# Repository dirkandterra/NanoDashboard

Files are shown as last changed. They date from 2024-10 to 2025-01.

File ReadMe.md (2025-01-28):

# _ESP_Dashboard_  

_This project uses the a Nano with a MCP2515 to drive a 2004 Dodge Intrepid Dashboard._

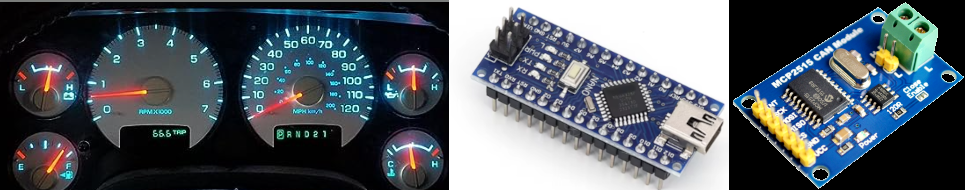
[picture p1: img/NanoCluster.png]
  

## How to use  

### Hardware Required  
* 2004 Dodge Intrepid Instrument Panel
* Connection:  

| Signal | Intrepid  | Nano |
|---|---|---|
| 5V | 5V		| 5V |
| GLDATA | GLDATA	| D4 |
| GLCLK | GLCLK 	| D5 |
| LightLatch| LightLatch| D6 |
| Gauge CS  | Gauge CS  | D7 |
| VFDDATA | VFDDATA | D8 |
| VFDCLK	| VFDCLK	| D9 |
| VFD Pls	| VFD Pls	| D10  |
| Backlight | UC_LMP_DRV| D2 |
| PB Input  | ODO PB | D3 |
| L Turn | C2-5		| A0 |
| R Turn | C1-8 | A1 |
| HighBeam  | C1-10 | A2 |
| OilPress  | C2-10 | A3 |
| ABS		| ??		| A4 |
| Airbag | ??		| A5 |
| GND | GND | D7 |

* MCP2515 Breakout Board
* Connection: 

| MCP2515 | Nano |
|---|---|
| INT |  - |
| SCK		| D13  |
| MOSI | D11  |
| MISO	 | D12  |
| CS to 5V  |  - |
| GND | GND  |
| 5V 	| 5V |

### Arduino Library Needed  

```
https://github.com/coryjfowler/MCP_CAN_lib.git
```

* MCP_CAN_lib

### Intrepid Dashboard Help

* Intrepid Schematic (Not Complete):  

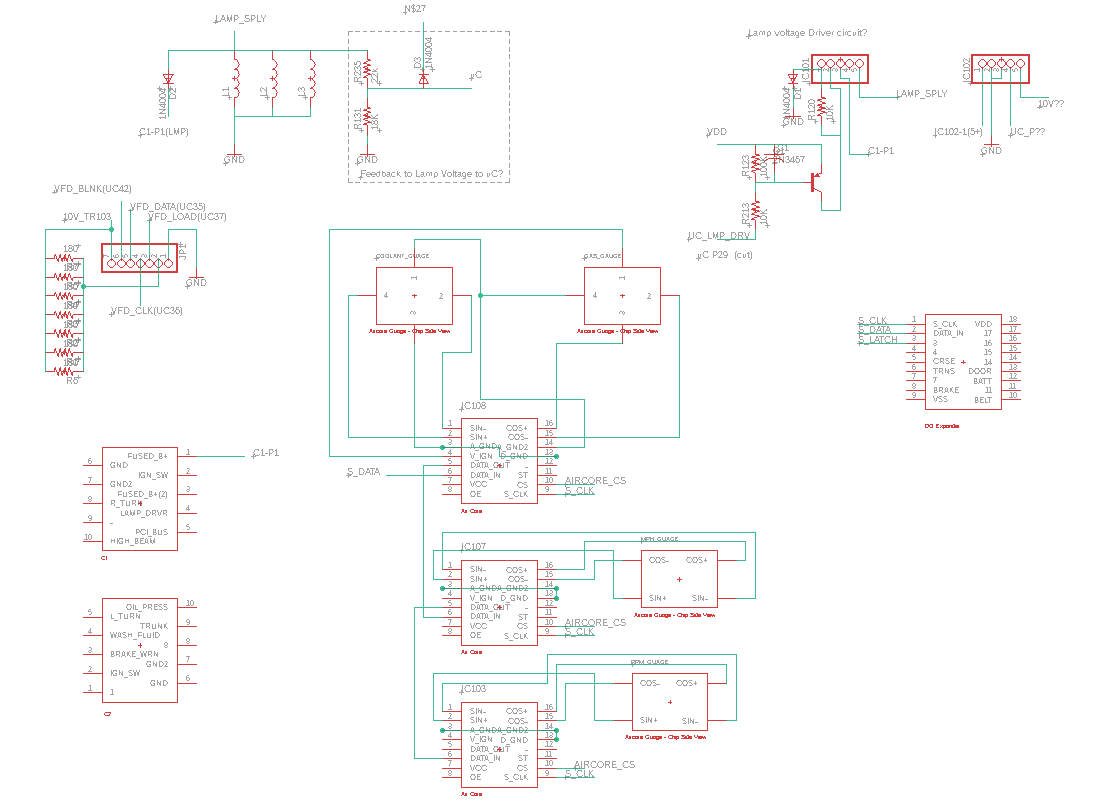
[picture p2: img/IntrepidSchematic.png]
IntrepidSchematic


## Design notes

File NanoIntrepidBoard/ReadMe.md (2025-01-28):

# _ESP_Dashboard_  

_This project uses the a Nano with a MCP2515 to drive a 2004 Dodge Intrepid Dashboard._

IntrepidSchematic  

## How to use  

### Hardware Required  
* 2004 Dodge Intrepid Instrument Panel
* Connection:  

| Signal | Intrepid  |ESP8266|
|---|---|---|
| 3.3V | NC		| VCC	|
| SCLK | D0(SCL) | GPIO14|
| VFDCLK	| VFDCLK	| Trans	| 
| MOSI | VFD/GLDATA| GPIO13|
| Gauge CS  | Gauge CS  | GPIO16|
| Light Pls | Light Pls | GPIO12|
| VFD Pls	| VFD Pls	| GPIO02|
| GND | GND | GND |

### Configure the project  

```
make menuconfig
```

* Set serial port under Serial Flasher Options.

### Build and Flash  

Build the project and flash it to the board, then run monitor tool to view serial output:

```
make -j4 flash monitor
```

(To exit the serial monitor, type ``Ctrl-]``.)

See the Getting Started Guide for full steps to configure and use ESP-IDF to build projects.

## Example Output  

* LOG:  

```
I (233) spi_oled: init gpio
I (235) gpio: GPIO[12]| InputEn: 0| OutputEn: 1| OpenDrain: 0| Pullup: 1| Pulldown: 0| Intr:0
I (239) gpio: GPIO[15]| InputEn: 0| OutputEn: 1| OpenDrain: 0| Pullup: 1| Pulldown: 0| Intr:0
I (251) spi_oled: init hspi
I (257) spi_oled: init oled
```

* Intrepid Schematic (Not Complete):  

  IntrepidSchematic

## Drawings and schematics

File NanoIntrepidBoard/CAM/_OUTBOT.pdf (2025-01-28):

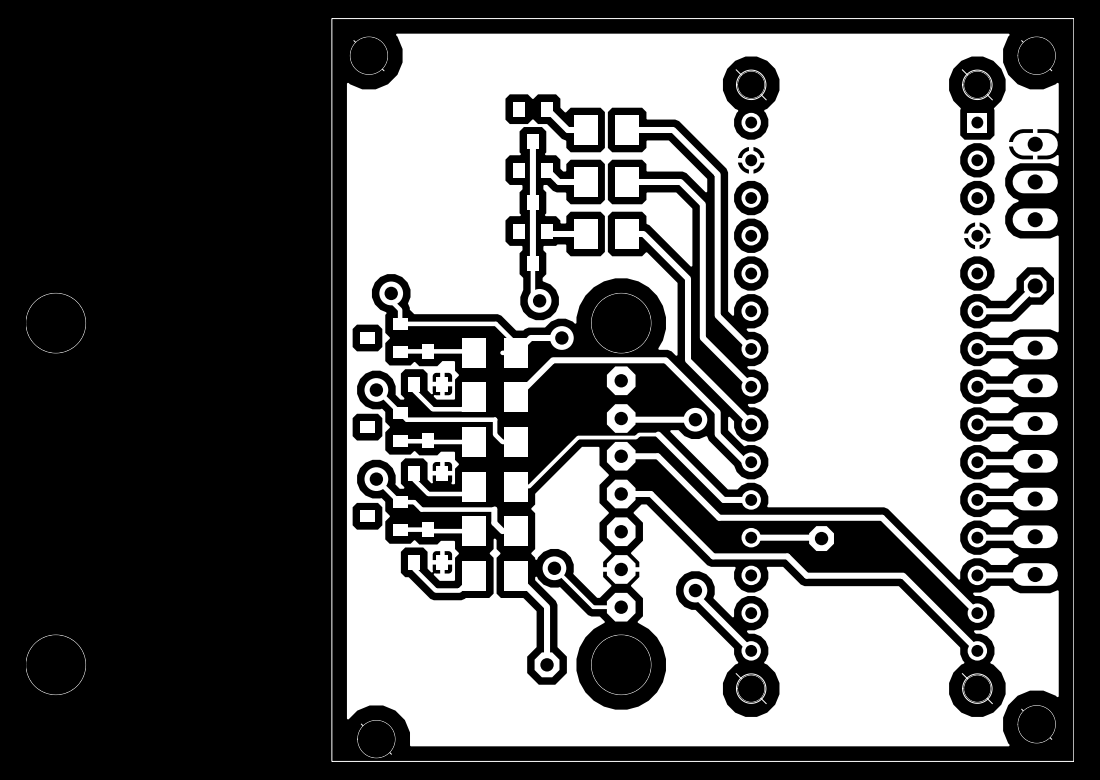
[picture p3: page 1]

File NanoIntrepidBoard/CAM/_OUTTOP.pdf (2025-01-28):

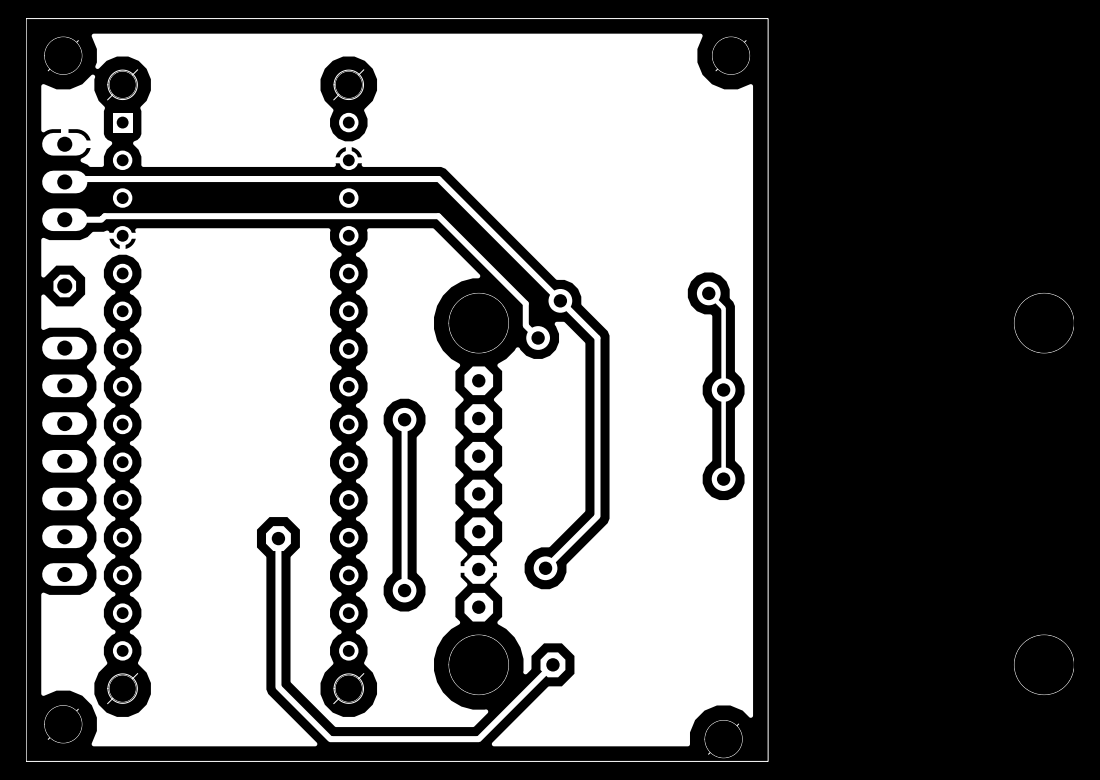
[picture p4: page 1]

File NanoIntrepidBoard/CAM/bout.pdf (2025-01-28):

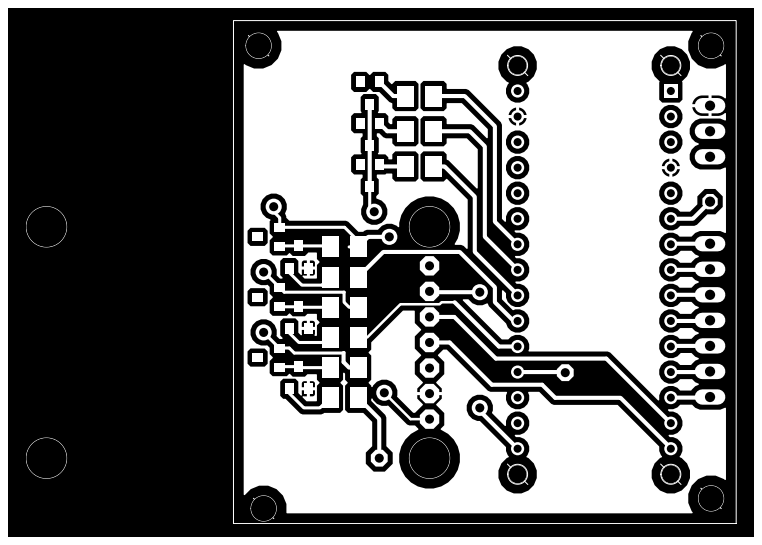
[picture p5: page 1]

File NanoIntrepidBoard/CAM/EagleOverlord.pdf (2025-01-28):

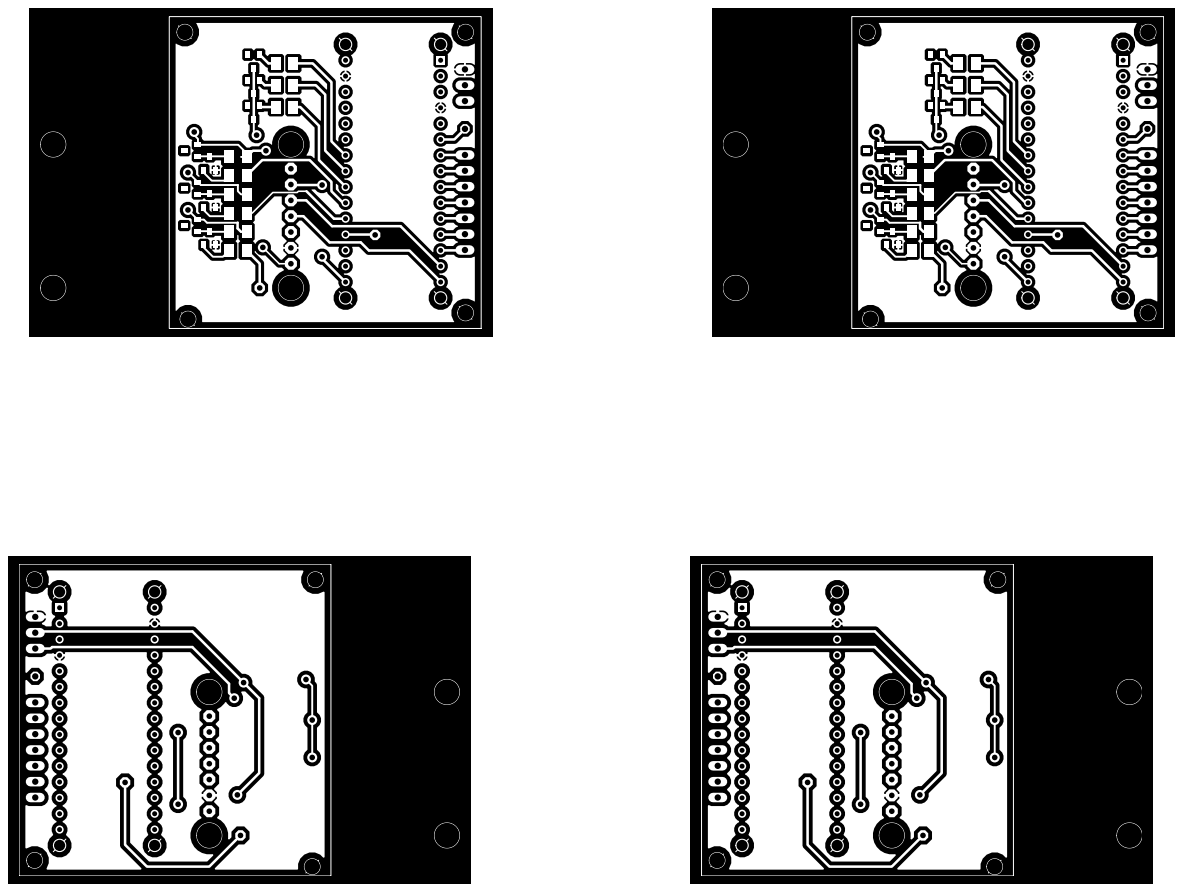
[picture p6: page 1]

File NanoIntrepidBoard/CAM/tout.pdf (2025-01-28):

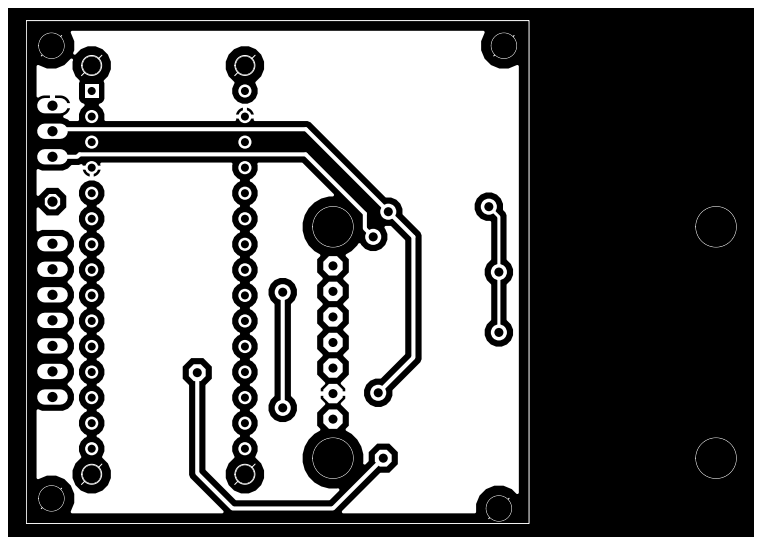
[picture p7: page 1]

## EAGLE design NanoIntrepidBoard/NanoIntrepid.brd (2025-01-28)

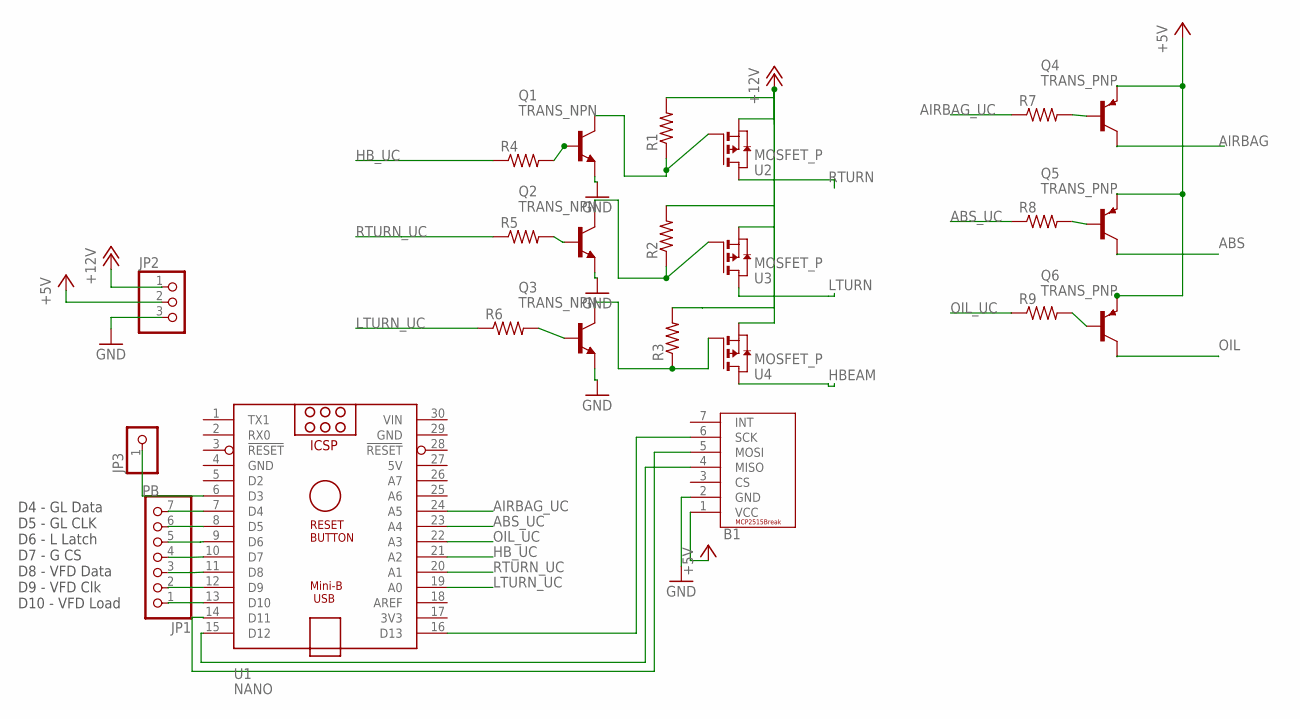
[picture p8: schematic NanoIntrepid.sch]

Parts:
B1: MCP2515_BREAKOUT
JP1: PINHD-1X7; 1X07
JP2: PINHD-1X3; 1X03
JP3: PINHD-1X1; 1X01
Q1, Q2, Q3: TRANS_NPN; SOT-23
Q4, Q5, Q6: TRANS_PNP; SOT-23
R1, R2, R3, R4, R5, R6, R7, R8, R9: R-US_M1206; M1206
U1: NANO
U2, U3, U4: MOSFET_P; SOT-23

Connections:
5V: U1.27 (5V)
+5V: B1.1 (VCC), JP2.2, Q4.3 (E), Q5.3 (E), Q6.3 (E)
+12V: JP2.1, R1.2, R2.2, R3.2, U2.2 (S), U3.2 (S), U4.2 (S)
ABS: Q5.2 (C)
ABS_UC: R8.1, U1.23 (A4)
AIRBAG: Q4.2 (C)
AIRBAG_UC: R7.1, U1.24 (A5)
GND: B1.2 (GND), JP2.3, Q1.2 (E), Q2.2 (E), Q3.2 (E), U1.4 (GND), U1.29 (GND)
HBEAM: U4.3 (D)
HB_UC: R4.1, U1.21 (A2)
LTURN: U3.3 (D)
LTURN_UC: R6.1, U1.19 (A0)
unnamed: B1.6 (SCK), U1.16 (D13)
unnamed: B1.4 (MISO), U1.15 (D12)
unnamed: B1.5 (MOSI), U1.14 (D11)
unnamed: JP1.7, U1.7 (D4)
unnamed: JP1.6, U1.8 (D5)
unnamed: JP1.5, U1.9 (D6)
unnamed: JP1.4, U1.10 (D7)
unnamed: JP1.3, U1.11 (D8)
unnamed: JP1.2, U1.12 (D9)
unnamed: JP1.1, U1.13 (D10)
unnamed: Q2.1 (B), R5.2
unnamed: Q1.1 (B), R4.2
unnamed: Q1.3 (C), R1.1, U2.1 (G)
unnamed: Q2.3 (C), R2.1, U3.1 (G)
unnamed: Q3.3 (C), R3.1, U4.1 (G)
unnamed: Q3.1 (B), R6.2
unnamed: Q4.1 (B), R7.2
unnamed: Q5.1 (B), R8.2
unnamed: Q6.1 (B), R9.2
OIL: Q6.2 (C)
OIL_UC: R9.1, U1.22 (A3)
PB: JP3.1, U1.6 (D3)
RTURN: U2.3 (D)
RTURN_UC: R5.1, U1.20 (A1)
VIN: U1.30 (VIN)

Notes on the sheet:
D4 - GL Data D5 - GL CLK D6 - L Latch D7 - G CS D8 - VFD Data D9 - VFD Clk D10 - VFD Load

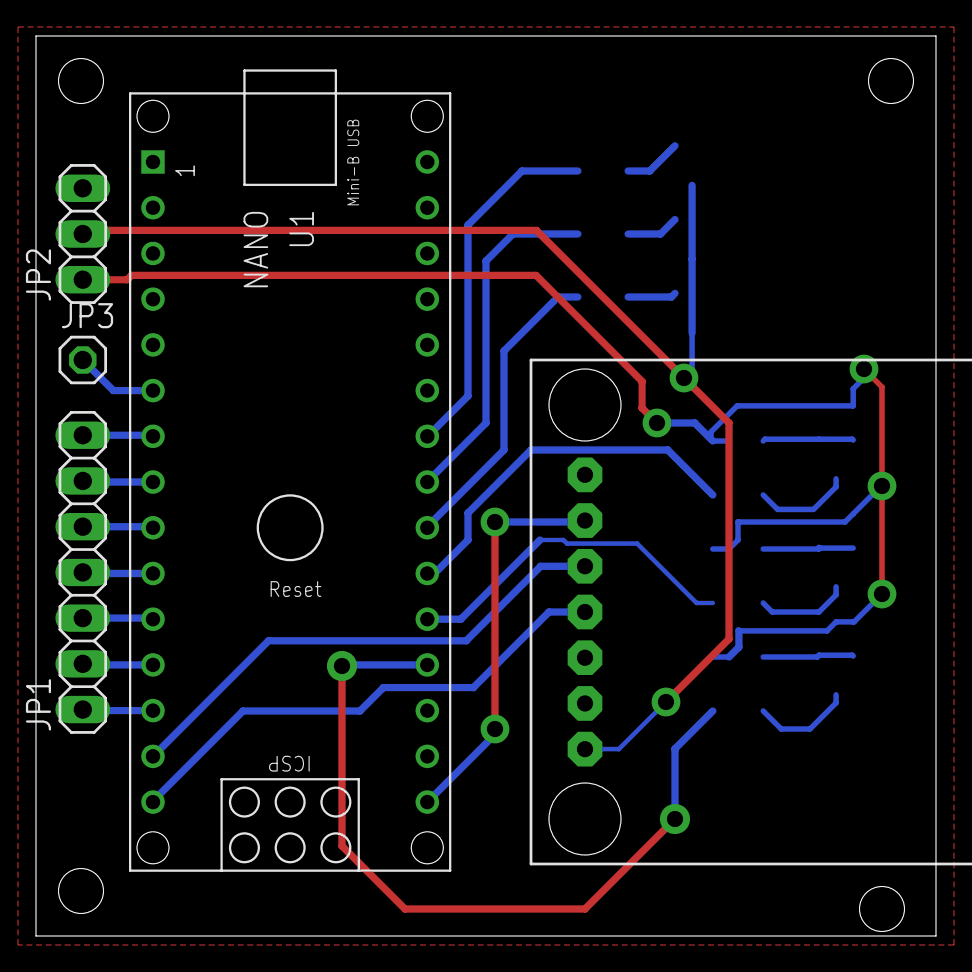
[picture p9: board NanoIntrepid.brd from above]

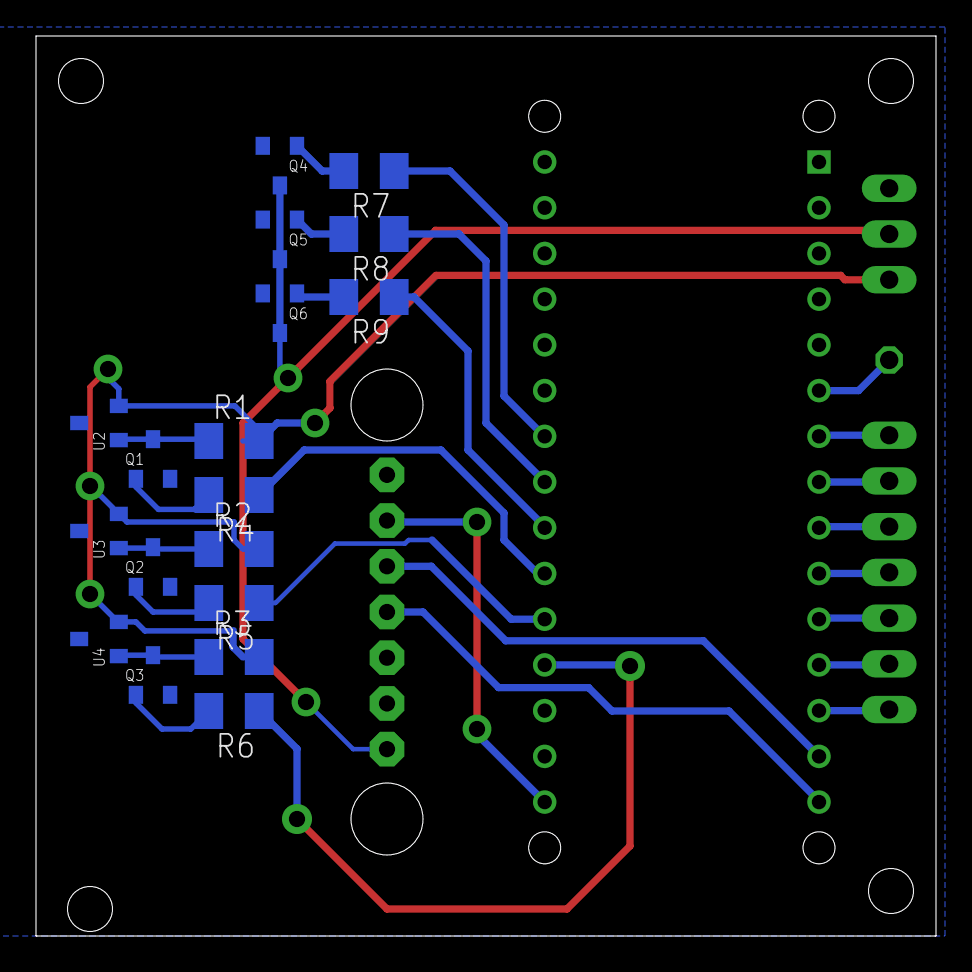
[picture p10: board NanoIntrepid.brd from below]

Board: 2 copper layers, 50.0 x 50.0 mm, 23 parts (18 on the bottom side), 29 nets.

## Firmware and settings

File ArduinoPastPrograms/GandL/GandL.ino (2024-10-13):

#include <avr/io.h>
#include "GandL.h"
#include "IntrVFD.h"

uint32_t timerGaugeAndLights=0;
uint32_t weatherInfoUpdate=0;
uint32_t startupTest=1;
uint8_t removeTest[8];
typedef struct rxBuff{
  uint8_t data[10];
  uint8_t rxPtr;
}rxBuff;

rxBuff rx232;
boolean stringComplete=false;

uint8_t timerCheck(uint32_t tmr, uint32_t setpoint){
  uint32_t now=millis();
  if(now>(tmr+setpoint)){
    return true;
  }
  else
  {
    return false;
  }
}

void handle232(void);
double del = 100000;

void setup() { 
  DDRD |= 0xF0; 
  DDRB |= 0x07;
  Serial.begin(38400); 
  rx232.rxPtr=0;
  Serial.println("Starting...");
  startupTest=millis()+3000;
    sendInfo(0, 700);
    sendInfo(1, 1200);
    sendInfo(2, 100);
    sendInfo(3, 100);
    sendInfo(4, 0xFFFF);
    printTextToVFD("888888",0,6,J_LEFT,vfd);
    sendVFD(vfd,1);
}

void loop() {
  //sendInfo(0, 20);
  if(stringComplete){
    stringComplete=false;
    handle232();
  }
  if(timerCheck(timerGaugeAndLights,50)){
    updateGuages_Lights();
    timerGaugeAndLights=millis();
  }
  if(timerCheck(weatherInfoUpdate,2000) && prepIt){
    weatherInfoUpdate=millis();
    vfdPrep();
    Serial.println("Zip");
    sendVFD(vfd,1);
  }
  if(timerCheck(startupTest,3000) && startupTest>0){
    startupTest=0;  //one time only
    sendInfo(0, 0);
    sendInfo(1, 0);
    sendInfo(2, 0);
    sendInfo(3, 0);
    sendInfo(4, 0x0);
    printTextToVFD("      ",0,6,J_LEFT,vfd);
    sendVFD(vfd,1);
  }
}

void serialEvent() {
  while (Serial.available()) {
    // get the new byte:
    char inChar = (char)Serial.read();
    
    if (inChar == '\r') {
      stringComplete = true;
    }
    else if(inChar=='\n'){
      
    }      
    else{
      rx232.data[rx232.rxPtr] = inChar;
      rx232.rxPtr++;
    }
  }
}

void handle232(){
  uint8_t dataLength=rx232.rxPtr;
  uint16_t multiplier=1, temp16=0;
  if(dataLength>1){
    switch(rx232.data[0]){
      case '0':
        dataLength-=1;   //Don't count the first byte identifier
        for(int ii=dataLength; ii>0; ii--){
            temp16+=(rx232.data[ii]-0x30)*multiplier;
            multiplier*=10;
        }
        Serial.println(temp16);  
        sendInfo(0, temp16);
        break;
     case '1':
        dataLength-=1;   //Don't count the first byte identifier
        for(int ii=dataLength; ii>0; ii--){
            temp16+=(rx232.data[ii]-0x30)*multiplier;
            multiplier*=10;
        }
        Serial.println(temp16);  
        sendInfo(1, temp16);
        break;
     case '2':
        dataLength-=1;   //Don't count the first byte identifier
        for(int ii=dataLength; ii>0; ii--){
            temp16+=(rx232.data[ii]-0x30)*multiplier;
            multiplier*=10;
        }
        Serial.println(temp16);  
        sendInfo(2, temp16);
        break;
     
    case '3':
        dataLength-=1;   //Don't count the first byte identifier
        for(int ii=dataLength; ii>0; ii--){
            temp16+=(rx232.data[ii]-0x30)*multiplier;
            multiplier*=10;
        }
        Serial.println(temp16);  
        sendInfo(3, temp16);
        break;      
     case '4':
        dataLength-=1;   //Don't count the first byte identifier
        for(int ii=dataLength; ii>0; ii--){
            temp16+=(rx232.data[ii]-0x30)*multiplier;
            multiplier*=10;
        }
        Serial.println(temp16);  
        sendInfo(4, temp16);
        break;
     case '5':
        dataLength-=1;   //Don't count the first byte identifier
        for(int ii=dataLength; ii>0; ii--){
            temp16+=(rx232.data[ii]-0x30)*multiplier;
            multiplier*=10;
        }
        testVFD(temp16);
        break;
     case '6':
        dataLength-=1;   //Don't count the first byte identifier 
        sendVFD(rx232.data,0);
        break;

     case '7':
        dataLength-=1;   //Don't count the first byte identifier
        for(int ii=dataLength; ii>0; ii--){
            temp16+=(rx232.data[ii]-0x30)*multiplier;
            multiplier*=10;
        }
        rx232.data[8]|=0x80;
        rx232.data[5]=rx232.data[4];
        rx232.data[4]=rx232.data[3];
        rx232.data[3]=rx232.data[2];
        rx232.data[2]=rx232.data[1];
        rx232.data[0]=' ';  
        rx232.data[1]=' ';  
        Serial.println(temp16);  
        sendInfo(1, temp16);
        printTextToVFD(rx232.data,0,6,J_LEFT,vfd);
        sendVFD(rx232.data,1);
        break;

     case '8':
        dataLength-=1;   //Don't count the first byte identifier 
        printTextToVFD("L",0,2,J_LEFT,vfd);
        printNumToVFD(1013,2,4,1,J_RIGHT,vfd);
        sendVFD(rx232.data,1);
        break;

      case '9':
        prepIt=!prepIt;
        break;
      case 'A':
        sendInfo(5,232);
        break;
      case 'B':
        sendInfo(5,590);
        break;
      default:
        break;
       
      
    }
  }
  rx232.rxPtr=0;

}

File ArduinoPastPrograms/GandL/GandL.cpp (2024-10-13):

//Guage and Lights Only
#include "RS232Decode.h"
#include "IntrVFD.h"

int gaugeData[25]={0,34,65,96,125,155,181,204,232,256,279,303,329,352,382,410,438,466,497,528,559,590,621,649,677};
int gaugeData2[25]={0,23,44,62,83,102,120,138,156,176,196};
char CBuffLen=0;
char t0_int;// = 0x30;
int t0_cyc=0;
char t0_disp;
char segrotate=1;
char digsel=2;
int rpmData=261;
int mphData=261;
int gasData=38;
int tempData=38;
int lightData=0;
char forecast[8]={0x64,0x3F,0x63,0x3E,0x62,0x3D,0x61,0x3C};
char mode=0;
int oldMPH=261;
int oldRPM=261;
uint8_t dectrip=0;
uint8_t vfd_count=0;
//261,5.25,22,41.1,61.8,80,96.5,113.5,936
int gypsyMath(int in);
int gypsyMath2(int in);
void vfdPrep(void);


int sendInfo(uint8_t gauge, uint16_t value){
	
	switch(gauge){
		
		case 0:
			rpmData=(int)(double(value)*12/7);
      rpmData=gypsyMath(rpmData);
			break;
	
		case 1:
			mphData=(int)value;
			mphData=gypsyMath(mphData);
			break;
		
		case 2:
			gasData=(int)value;
      gasData=gypsyMath2(gasData);
			break;
			
		case 3:
			tempData=(int)value;
      tempData=gypsyMath2(tempData);
			break;

    case 5:
      mphData=value;
      break;

		default:
		case 4:
			lightData=(int)value;
			break;
	}

}

//****************************************************
void updateGuages_Lights(){
  int diff;

  diff=rpmData-oldRPM;
  if (diff<100 && diff>-100) {oldRPM=rpmData;}
  else {oldRPM=oldRPM+diff/6;}

  diff=mphData-oldMPH;
  if (diff<100 && diff>-100) {oldMPH=mphData;}
  else {oldMPH=oldMPH+diff/6;}


  gaugeString[0]=oldMPH/256;
  gaugeString[1]=oldMPH%256;
  gaugeString[2]=oldRPM/256;
  gaugeString[3]=oldRPM%256;
  gaugeString[4]=tempData/256;
  gaugeString[5]=tempData%256;
  gaugeString[6]=gasData/256;
  gaugeString[7]=gasData%256;
  sendToGauges();

  lightString[0]=lightData/256;
  lightString[1]=lightData%256;
  sendToLights();
}
//####################################################
int sendVFD(uint8_t *c, uint8_t n){
	clearDisp();
    /*vfd[6]=c[7];
    vfd[7]=c[8];
    vfd[5]=c[1];
    vfd[4]=c[2];
    vfd[3]=c[3];
    vfd[2]=c[4];
    vfd[1]=c[5];
    vfd[0]=c[6];*/
    if(n){
	    smarterPopulateVFD();
    }else{
      populateVFD();
    }
	sendVFDDimming();
	senddispToVFD();
	vfd_count++;
	if(vfd_count>7)
		vfd_count=0;
}

//####################################################
int testVFD(uint16_t value){
	uint8_t carry=0, oldcarry=0;
	//clearDisp();
	
	if(vfdString[6]&0x80 || value)
		oldcarry=1;
	
	for(int ii=0; ii<8; ii++){
		carry=0;
		if(vfdString[ii]&0x80){
			carry=1;
		}
		vfdString[ii]<<=1;
		if(oldcarry)
			vfdString[ii]|=0x01;
		else
			vfdString[ii]&=0xFE;
		
		oldcarry=carry;
	}

	sendVFDDimming();
	senddispToVFD();

}

//####################################################
void vfdPrep()
{

	sendInfo(2,vfd_count*10);
	printNumToVFD(forecast[vfd_count],2,4,0,J_RIGHT,vfd);

	if(vfd_count%2==0)
	{
		 printTextToVFD("HI",0,2,J_LEFT,vfd);
	}

	else
	{
    printTextToVFD("LO",0,2,J_LEFT,vfd);
	}

		// Set Trans select to show day and light up "PRN D3L"
	if (vfd_count<2)
	{
		setVfdExtra(vfdPRN,1);
    setVfdExtra(vfdD3L,1);
    setVfdExtra(vfdD,0);
		setVfdExtra(vfdP,1);
	}
		else if (vfd_count<4)
	{
		setVfdExtra(vfdPRN,1);
    setVfdExtra(vfdD3L,1);
		setVfdExtra(vfdP,0);
    setVfdExtra(vfdR,1);
	}
	else if (vfd_count<6)
	{
		setVfdExtra(vfdPRN,1);
    setVfdExtra(vfdD3L,1);
		setVfdExtra(vfdR,0);
    setVfdExtra(vfdN,1);
	}
	else
	{
		setVfdExtra(vfdPRN,1);
    setVfdExtra(vfdD3L,1);
		setVfdExtra(vfdN,0);
    setVfdExtra(vfdD,1);
	}	
      Serial.print(vfd[5],HEX);
      Serial.print(vfd[4],HEX);
      Serial.print(vfd[3],HEX);
      Serial.print(vfd[2],HEX);
      Serial.print(vfd[1],HEX);
      Serial.println(vfd[0],HEX);	

}

int gypsyMath(int in)
{
if (in>=1200)
	{
		return 937;	//676+261
	}
	else
	{
		int i=in/50;
		i=((in%50)*(gaugeData[i+1]-gaugeData[i]))/50 +gaugeData[i];
		return (i+261);
	}
}

int gypsyMath2(int in)
{
if (in>=100)
  {
    return 232;  //38+192
  }
  else
  {
    int i=in/10;
    i=((in%10)*(gaugeData2[i+1]-gaugeData2[i]))/10 +gaugeData2[i];
    return (i+38);
  }
}

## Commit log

2024-09-19 Old Arduino Test Codes
2024-09-19 Add MCP2515 library
    [MCP2515Calc.xlsx]
2024-10-14 Added Baseboard for Nano and MCP2515
    [NanoIntrepid.brd, NanoIntrepid.sch]
2024-10-15 Fixed some Eagle Library mistakes and started laying out board
    [NanoIntrepid.brd, NanoIntrepid.sch]
2024-10-16 Added backlight pin to readme
2024-10-16 Worked on board files
    [NanoIntrepid.brd, NanoIntrepid.sch]
2024-12-01 Finishing board file
    [NanoIntrepid.brd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]
